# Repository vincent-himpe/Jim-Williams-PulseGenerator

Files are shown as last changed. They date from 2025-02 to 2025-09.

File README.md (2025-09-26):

# Jim-Williams-PulseGenerator
 Jim Williams Pulsegenerator, SiliconvalleyGarage Edition

## MK-III Features:

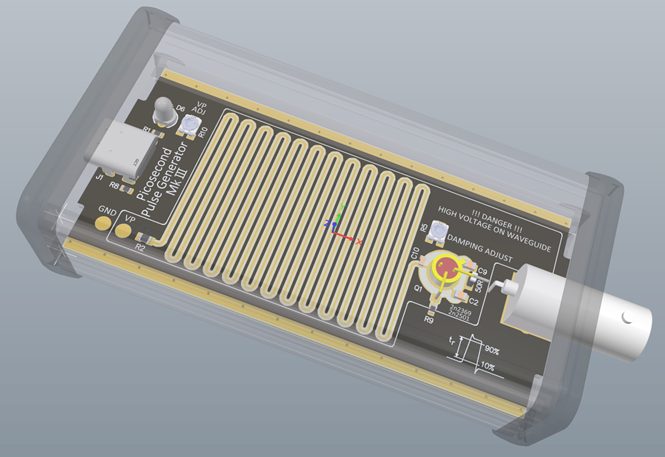
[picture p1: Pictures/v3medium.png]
mk-iii


The Mark-III is a big rework

- Switched to a metal case
- Switched to a BNC connector with floating center electrode
- Added damping adjust to compensate overshoot
- Reworked the waveguie "long capacitor" to take advantage of 4 layer board
- Different swithing regulator that is much cheaper than the LT1377.
- 5-stage high voltage cascade
- trimming adjustment for avalanche voltage
- USB-C power connection. No more batteries.
- Endcaps for both sides as a predrilled PCB that fit the Hammond Enclosure
  
## Layout

The Board is a 4 layer PCB that can easily be produced by the likes of JLCPCB or PCBway.  A full production pack (Gerber / NCdrill, BOM , Pick and place ) is available. 

## Assembly

The Bom and pick and place is included for assembly using LCSC parts at JLCPCB. The BOM also includes MOUSER part numbers

## Source Files

All source files are available in Altium Format. That's what i know, have and use. Other CAD programs most likely can import those. So you can modify.

## License

The project is PUBLIC DOMAIN. Do as you please. No warranties, As-Is
Creative Commons Zero.

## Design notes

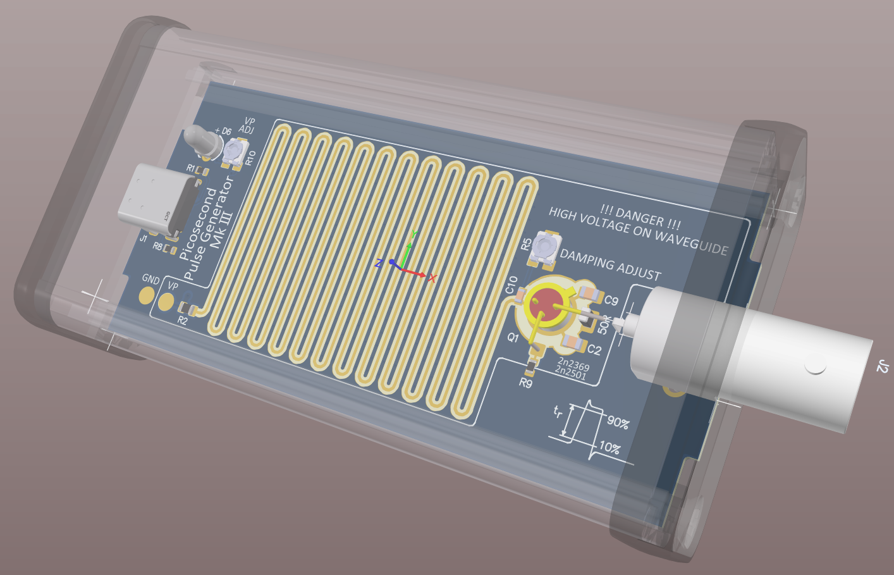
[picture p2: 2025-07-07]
Pictures/MK-III.png

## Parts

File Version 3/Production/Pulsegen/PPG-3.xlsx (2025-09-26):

Description | Designator | Quantity | LCSC
CAPACITOR,CERAMIC,470nF,250V,X7R,1210, CAPACITOR,CERAMIC,2pF,250V,C0G,0805,HIQ, CAPACITOR,CERAMIC,10pF,50V,C0G,0603, DIODE,SCHOTTKY,150V,1A,SK115,DO214AC(SMA), LED,TH,GREEN,42mCd,3MM, CONN,BNC,RA, ENCLOSURE,ALU.EXTRUDED,3.2inX1.8inX0.99in, TRANSISTOR, 2N2369 OR 2N2501, GOLD PINS, NOT 'A' VERSION, RESISTOR,1M,1%,125mW,0805, RESISTOR,12K,1%,100mW,0603 (1608), RES,TRIM,SMD,100R, RESISTOR,1K2,1%,100mW,0603 (1608), RES,TRIM,SMD,10K, PMIC,BOOST,LM2733,600KHz,SOT23-5 | C1, C2, C3, C4, C7, C8, C9, C10, D1, D2, D3, D4, D5, D6, J2, M1, Q1, R2, R4, R5, R6, R10, U1 | 23
CAPACITOR,CERAMIC,10uF,25V,X5R,0805 | C5, C6, C11, C12 | 4 | C3039694
CAPACITOR,CERAMIC,1nF,250V,X7R,0603 | C13 | 1 | C277510
FERRITE,1KZ@100MHz,0R2DC,0603 | FB1 | 1 | C160982
CONN,USB-C,16P,RA,TH,8.94X9.17 | J1 | 1 | C7095263
IND,10uH,1.2A,3X3, LQH3NPZ100MMEL | L1 | 1 | C701168
RESISTOR,5K1,1%,100mW,0603 (1608) | R1, R8 | 2 | C105580
RESISTOR,1K,1%,100mW,0603 (1608) | R3 | 1 | C22548
RESISTOR,4K7,1%,100mW,0603 (1608) | R7 | 1 | C99782
RESISTOR,10K,1%,100mW,0603 (1608) | R9 | 1 | C98220

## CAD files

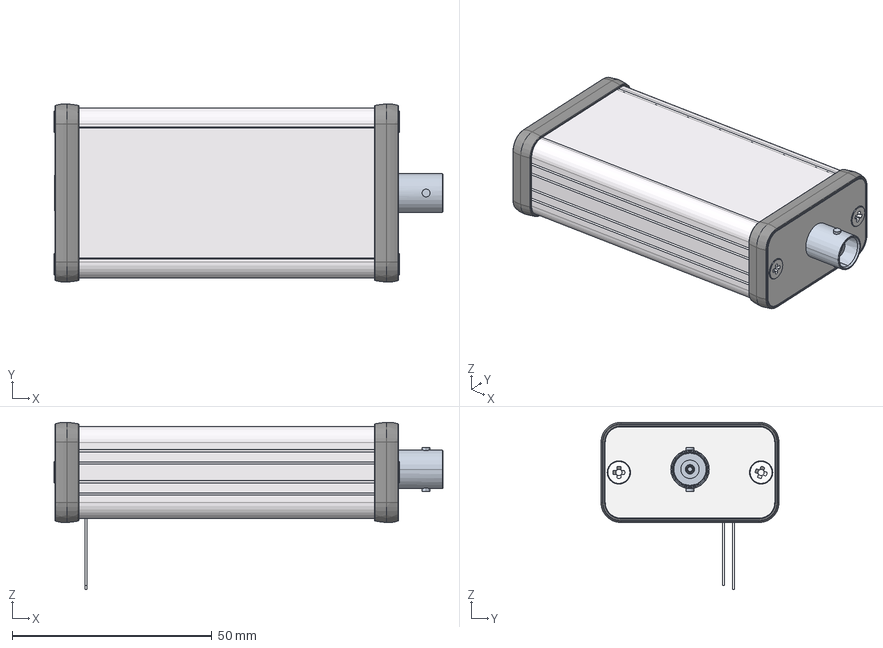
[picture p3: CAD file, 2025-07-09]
Version 3/JWpulsegen-V3.step
97.4 x 44.6 x 41.9 mm
MLCC capacitor 0603 - 0.5mm x 2
15103xxx
Chip Inductor 0603
MLCC capacitor 0805 - 0.85mm x 6
MLCC capacitor 1210 - 2.0mm x 5
SMA (DO-214AC) x 5
SOT23-5
SW3dPS-R0603 x 7
LQH3NPZ100MMEL
to18
User Library-1206 SMD Resistor
User Library-R0805
USB4085-GF-A_PART1
GCT
Extrusion Tube w. Inlay 80mm
Bezel Open x 2
End Plate x 2
1455 screw x 4

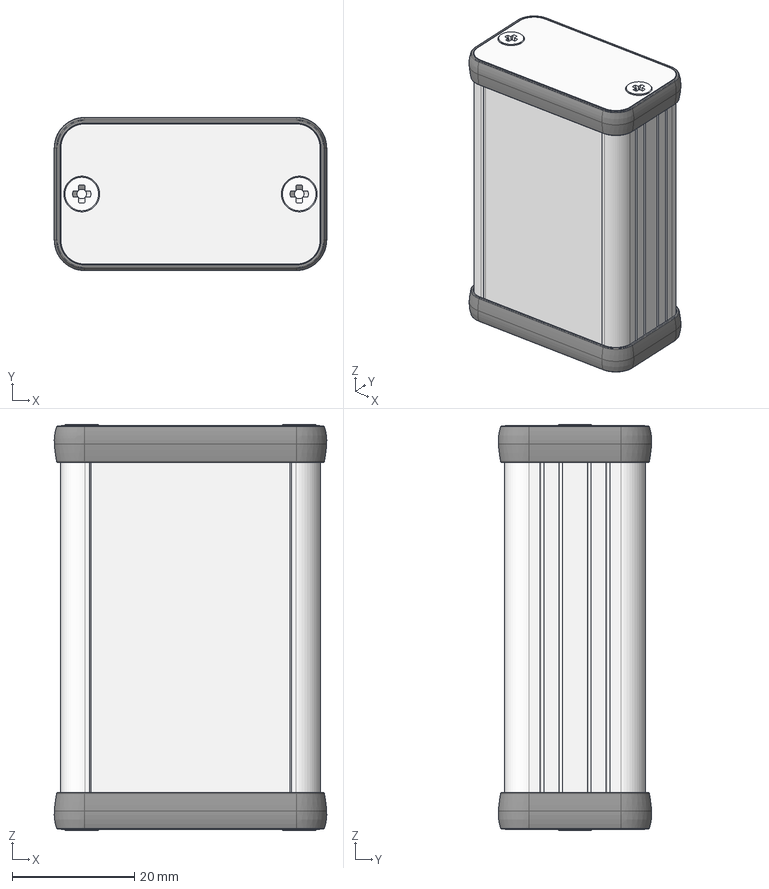
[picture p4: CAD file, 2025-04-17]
Version 3/STEP files/1455D601.stp
44.6 x 25.1 x 66.5 mm
Extrusion Tube w. Inlay 60mm
Bezel Open x 2
End Plate x 2
1455 screw x 4

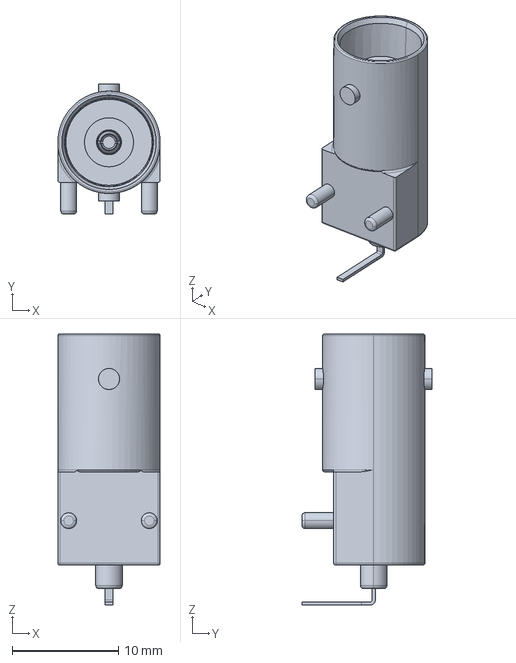
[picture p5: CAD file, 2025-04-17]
Version 3/STEP files/731000105.stp
9.65 x 12.3 x 25.6 mm

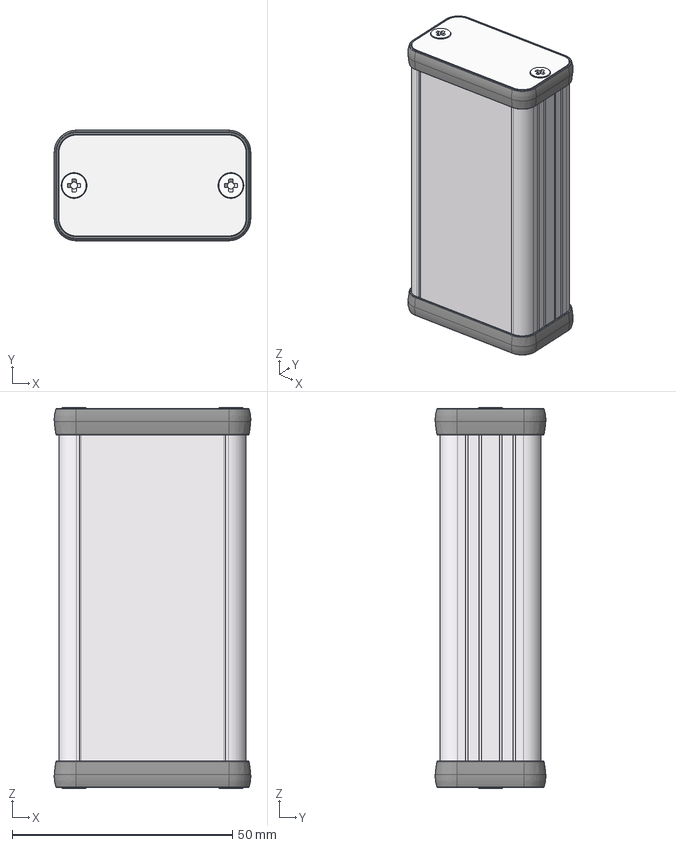
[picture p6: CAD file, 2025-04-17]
Version 3/STEP files/1455D801.stp
44.6 x 25.1 x 86.5 mm
Extrusion Tube w. Inlay 80mm
C Bezel Open x 2
C End Plate x 2
1455 screw x 4

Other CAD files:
Jim Williams Pulsegen/pulsegen-v2.DWG

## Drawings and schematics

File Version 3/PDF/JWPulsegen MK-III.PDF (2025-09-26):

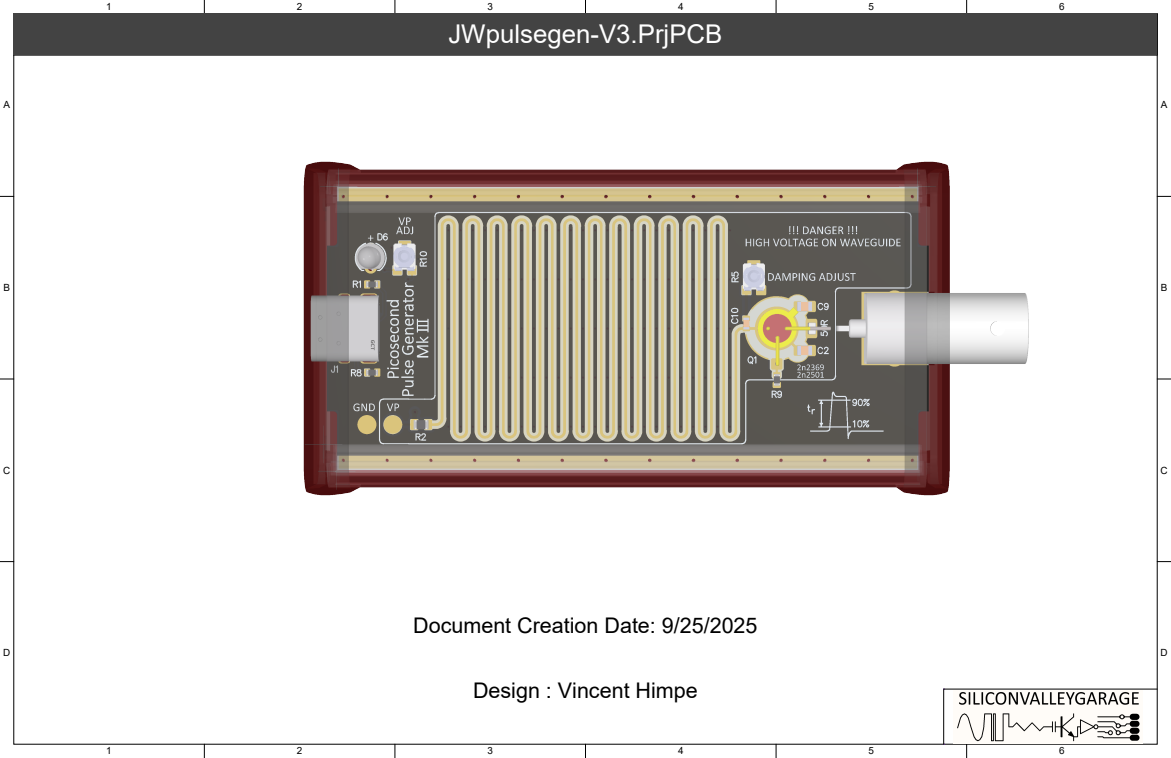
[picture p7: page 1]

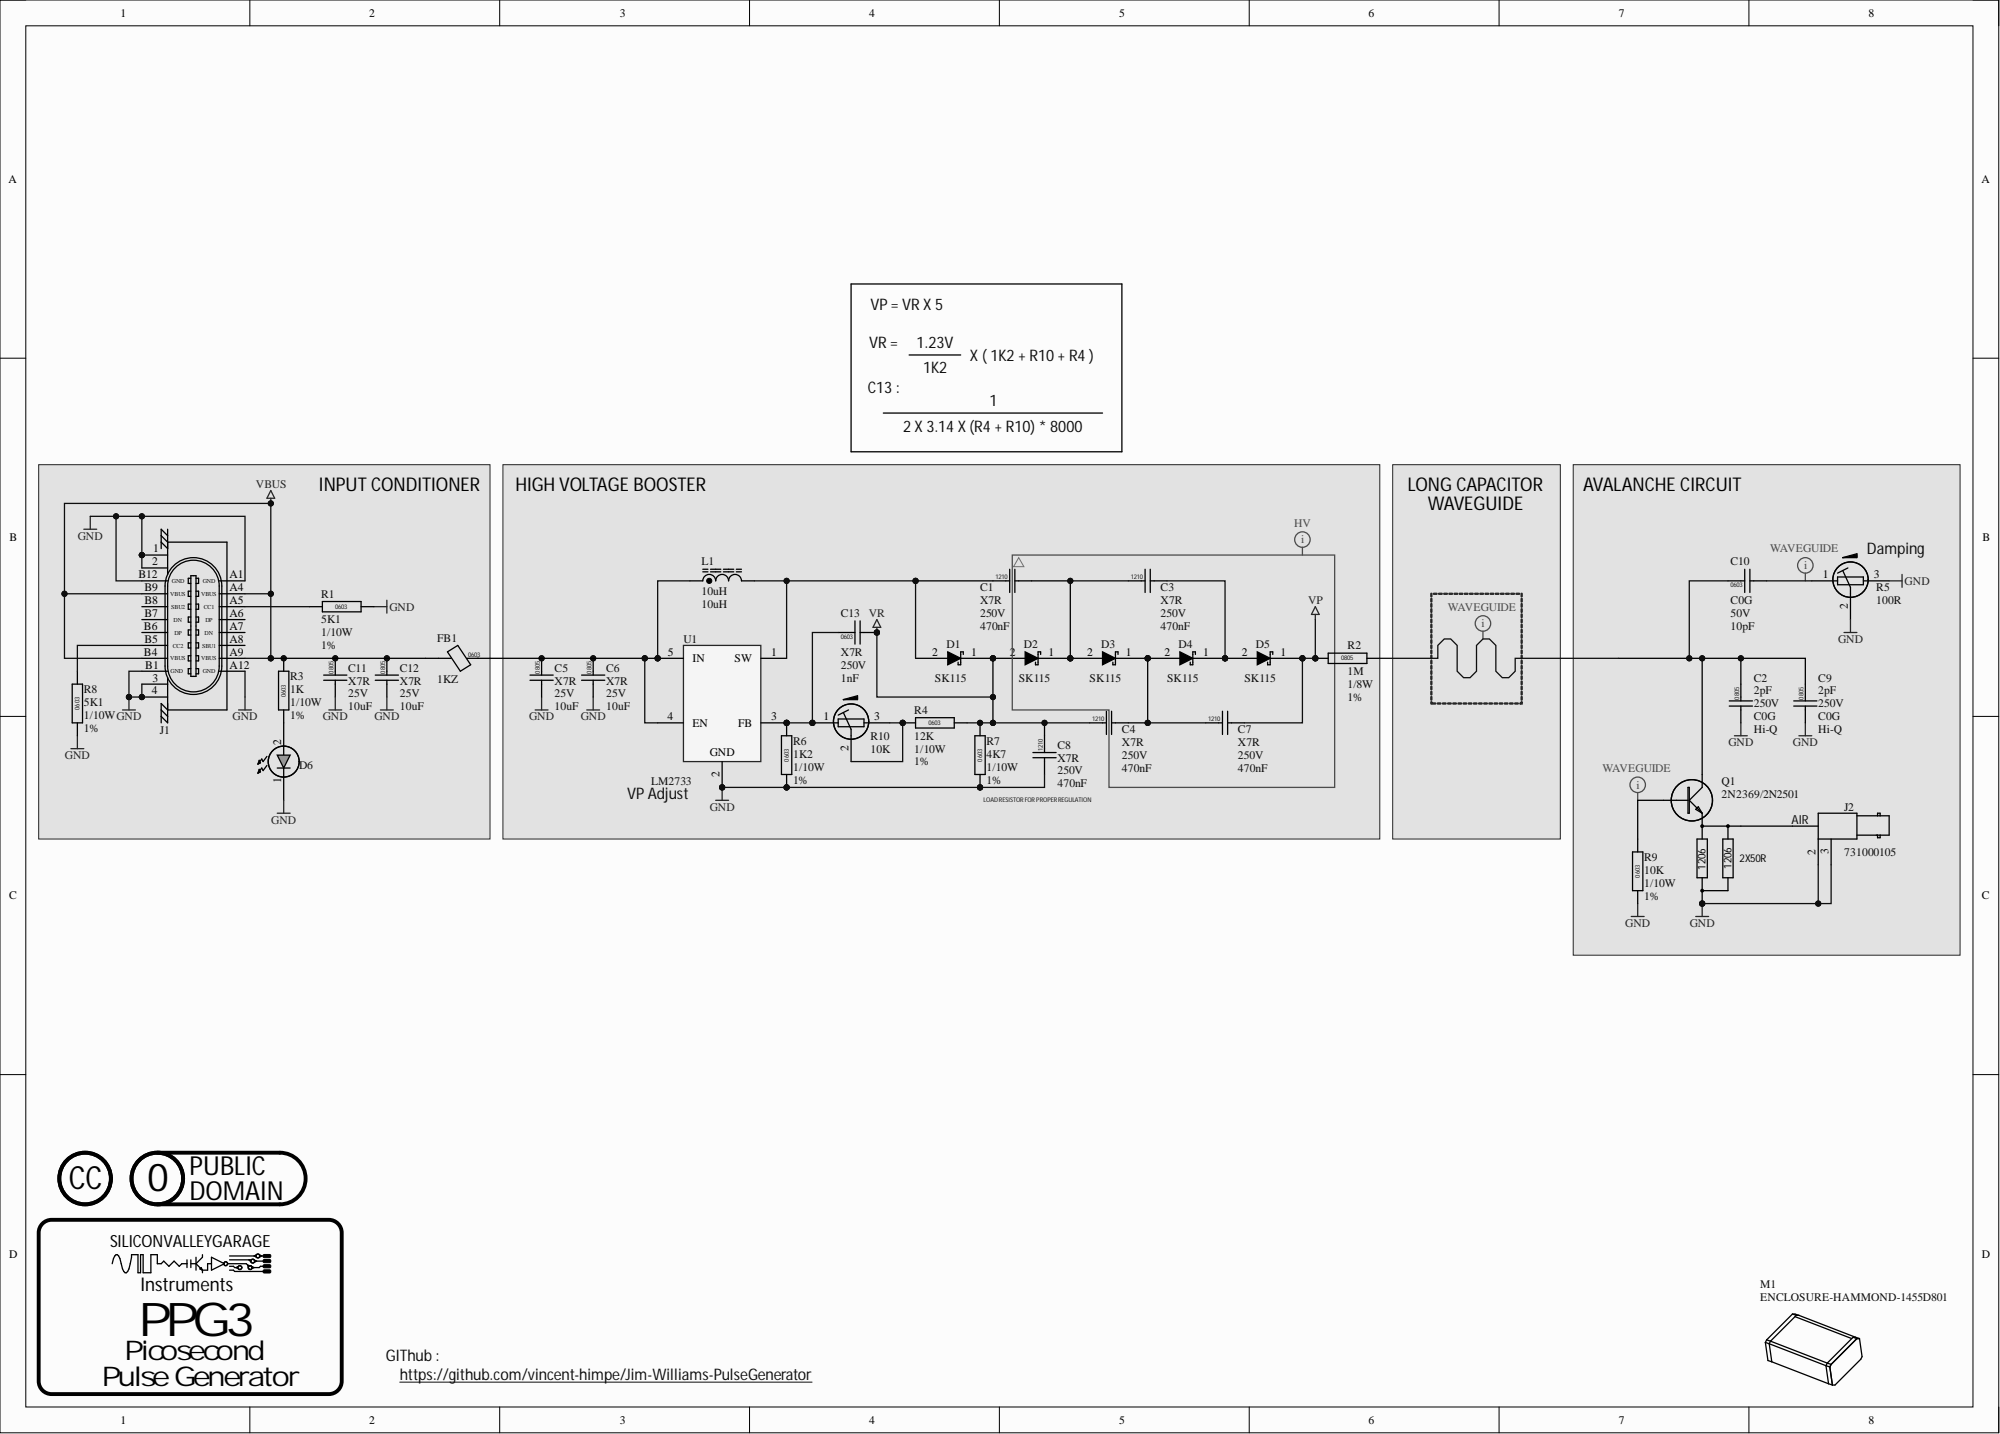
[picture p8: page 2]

LOADRESISTOR FOR PROPER REGULATION

GIThub :
https://github.com/vincent-himpe/Jim-Williams-PulseGenerator

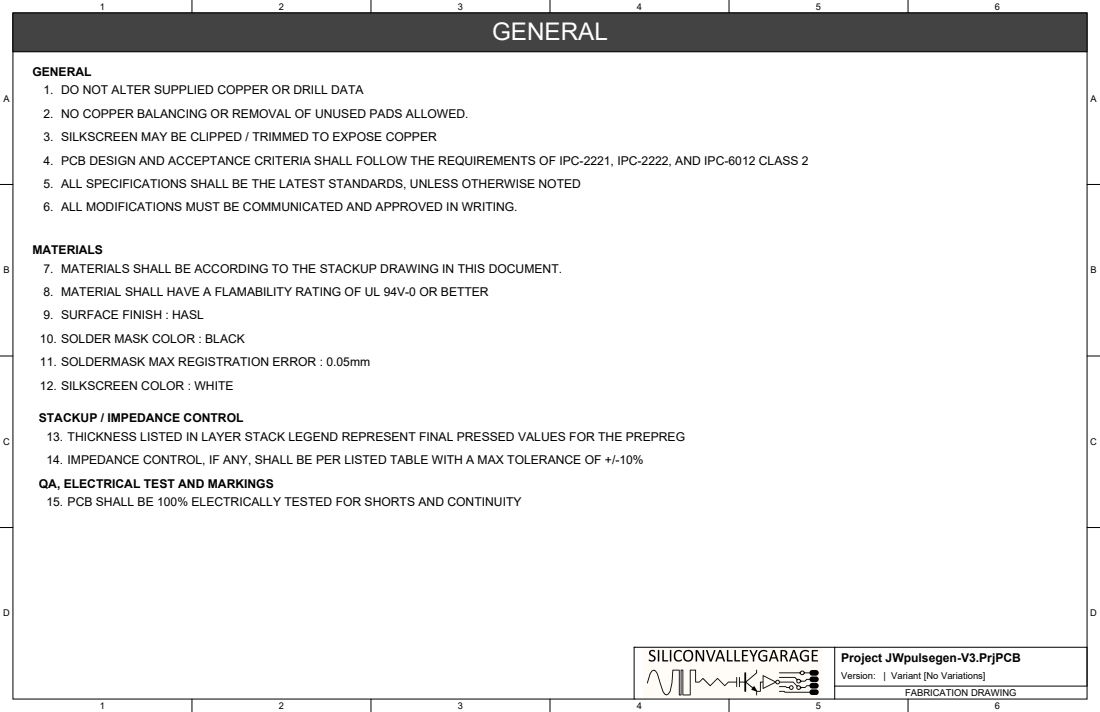
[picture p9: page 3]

GENERAL
1. DO NOT ALTER SUPPLIED COPPER OR DRILL DATA
2. NO COPPER BALANCING OR REMOVAL OF UNUSED PADS ALLOWED.
3. SILKSCREEN MAY BE CLIPPED / TRIMMED TO EXPOSE COPPER
4. PCB DESIGN AND ACCEPTANCE CRITERIA SHALL FOLLOW THE REQUIREMENTS OF IPC-2221, IPC-2222, AND IPC-6012 CLASS 2
5. ALL SPECIFICATIONS SHALL BE THE LATEST STANDARDS, UNLESS OTHERWISE NOTED
6. ALL MODIFICATIONS MUST BE COMMUNICATED AND APPROVED IN WRITING.

MATERIALS
7. MATERIALS SHALL BE ACCORDING TO THE STACKUP DRAWING IN THIS DOCUMENT.
8. MATERIAL SHALL HAVE A FLAMABILITY RATING OF UL 94V-0 OR BETTER
9. SURFACE FINISH : HASL
10. SOLDER MASK COLOR : BLACK
11. SOLDERMASK MAX REGISTRATION ERROR : 0.05mm
12. SILKSCREEN COLOR : WHITE

STACKUP / IMPEDANCE CONTROL
13. THICKNESS LISTED IN LAYER STACK LEGEND REPRESENT FINAL PRESSED VALUES FOR THE PREPREG
14. IMPEDANCE CONTROL, IF ANY, SHALL BE PER LISTED TABLE WITH A MAX TOLERANCE OF +/-10%
QA, ELECTRICAL TEST AND MARKINGS
15. PCB SHALL BE 100% ELECTRICALLY TESTED FOR SHORTS AND CONTINUITY

Project JWpulsegen-V3.PrjPCB
Version: | Variant [No Variations]

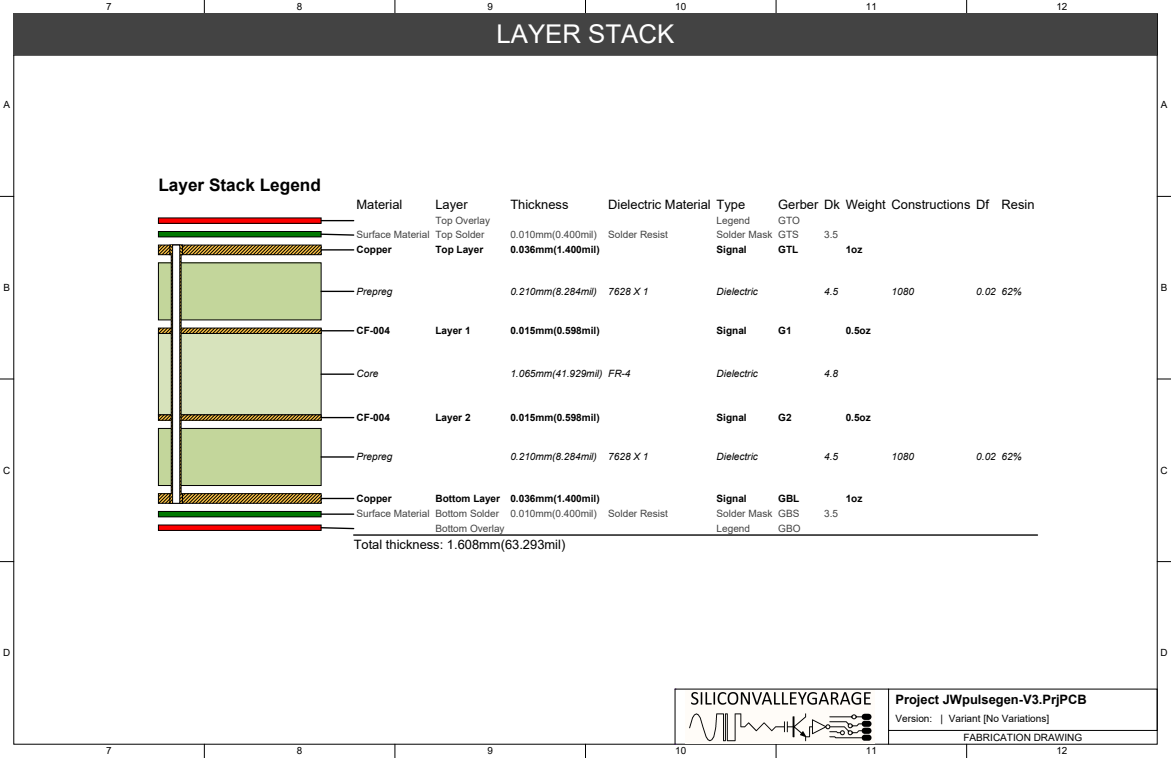
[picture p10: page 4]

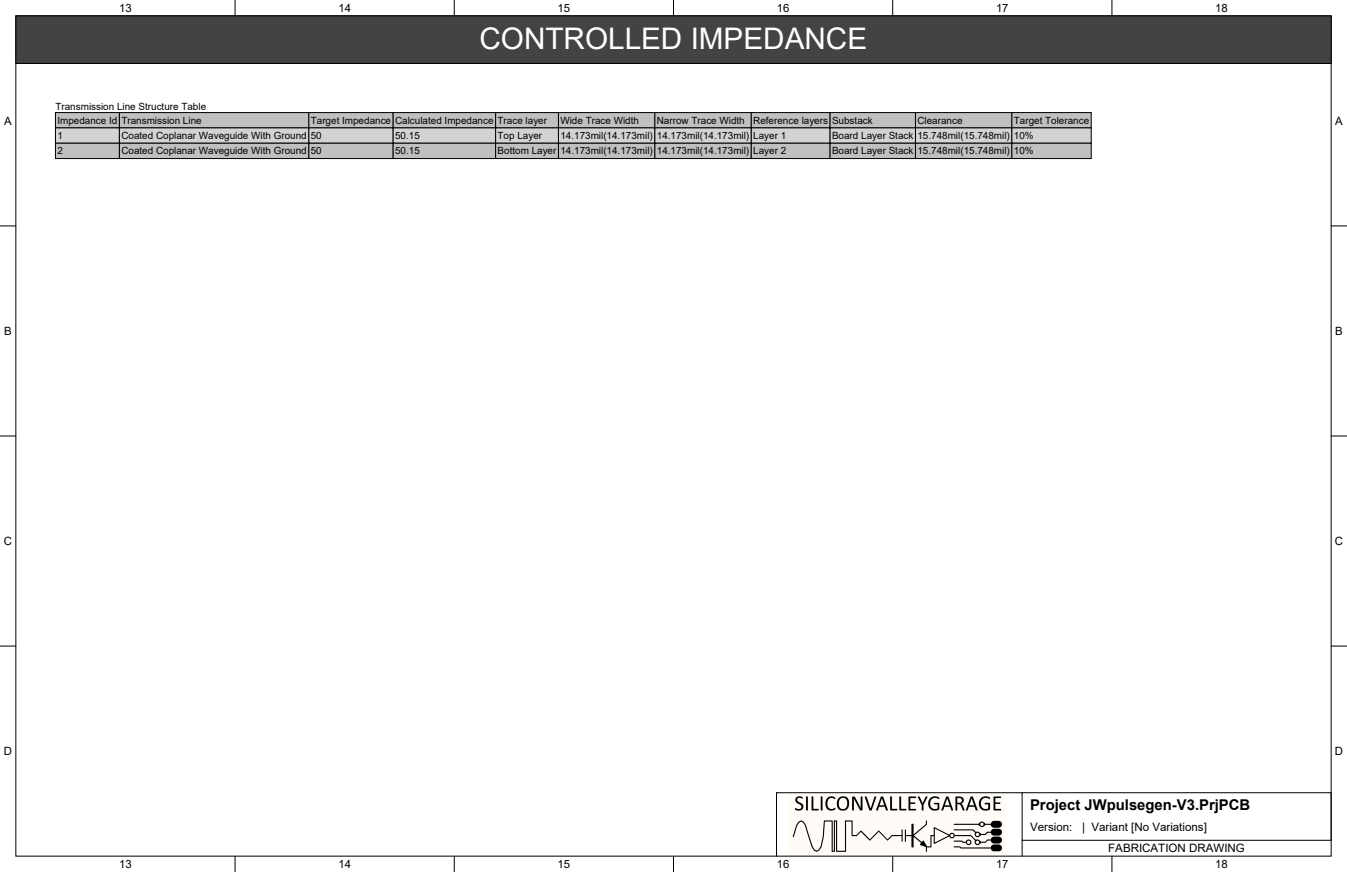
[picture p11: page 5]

Transmission Line Structure Table

Impedance Id | Transmission Line | Target Impedance | Calculated Impedance | Trace layer | Wide Trace Width | Narrow Trace Width | Reference layers | Substack | Clearance | Target Tolerance
1 | Coated Coplanar Waveguide With Ground | 50 | 50.15 | Top Layer | 14.173mil(14.173mil) | 14.173mil(14.173mil) | Layer 1 | Board Layer Stack | 15.748mil(15.748mil) | 10%
2 | Coated Coplanar Waveguide With Ground | 50 | 50.15 | Bottom Layer | 14.173mil(14.173mil) | 14.173mil(14.173mil) | Layer 2 | Board Layer Stack | 15.748mil(15.748mil) | 10%

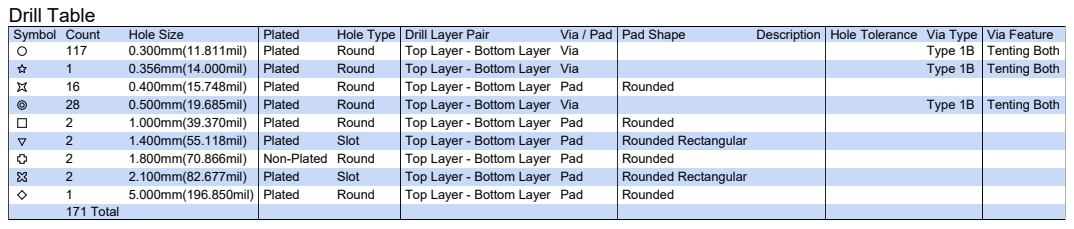
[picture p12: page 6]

Symbol | Count | Hole Size | Plated | Hole Type | Drill Layer Pair | Via / Pad | Pad Shape | Description | Hole Tolerance | Via Type | Via Feature

117 | 0.300mm(11.811mil) | Plated | Round | Top Layer - Bottom Layer | Via | | | | Type 1B | Tenting Both
1 | 0.356mm(14.000mil) | Plated | Round | Top Layer - Bottom Layer | Via | | | | Type 1B | Tenting Both
16 | 0.400mm(15.748mil) | Plated | Round | Top Layer - Bottom Layer | Pad | Rounded
28 | 0.500mm(19.685mil) | Plated | Round | Top Layer - Bottom Layer | Via | | | | Type 1B | Tenting Both
2 | 1.000mm(39.370mil) | Plated | Round | Top Layer - Bottom Layer | Pad | Rounded
2 | 1.400mm(55.118mil) | Plated | Slot | Top Layer - Bottom Layer | Pad | Rounded Rectangular
2 | 1.800mm(70.866mil) | Non-Plated | Round | Top Layer - Bottom Layer | Pad | Rounded
2 | 2.100mm(82.677mil) | Plated | Slot | Top Layer - Bottom Layer | Pad | Rounded Rectangular
1 | 5.000mm(196.850mil) | Plated | Round | Top Layer - Bottom Layer | Pad | Rounded
171 Total

Drill Drawing View (Scale 4:1)

LAYER VIEW : TOP LAYER

LAYER VIEW : MID LAYER 1

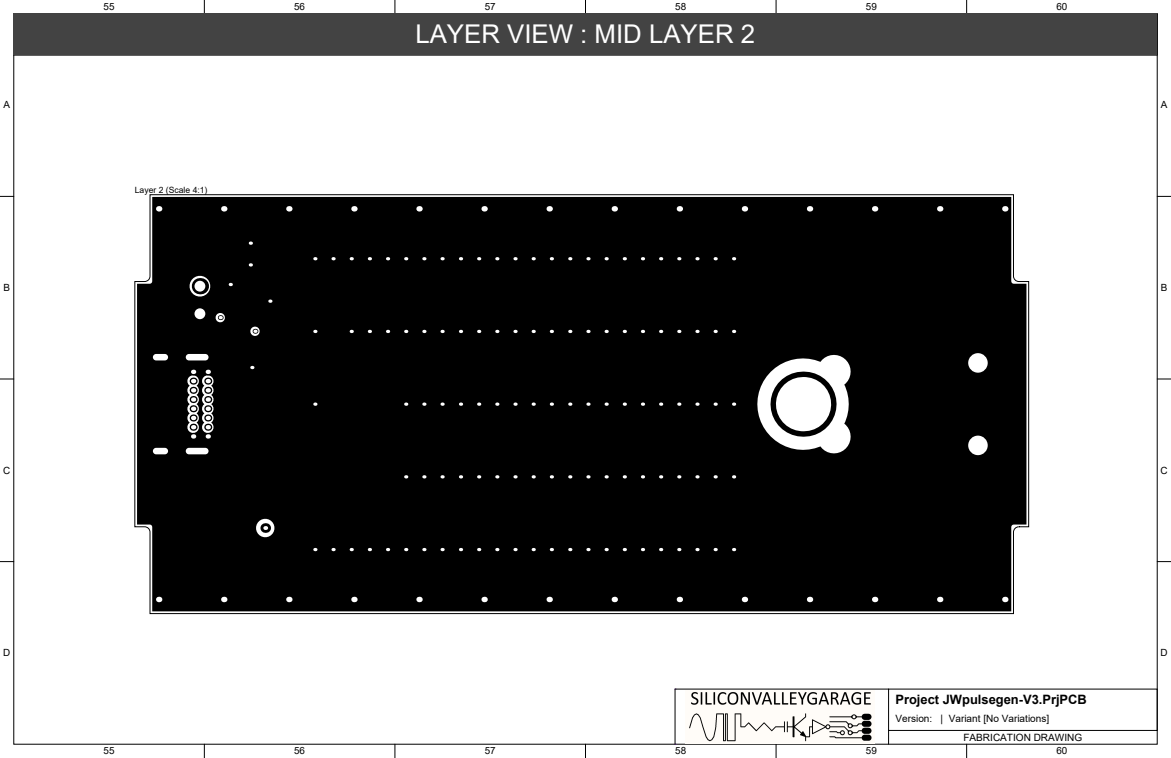
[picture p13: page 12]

LAYER VIEW : MID LAYER 2

LAYER VIEW : BOTTOM LAYER

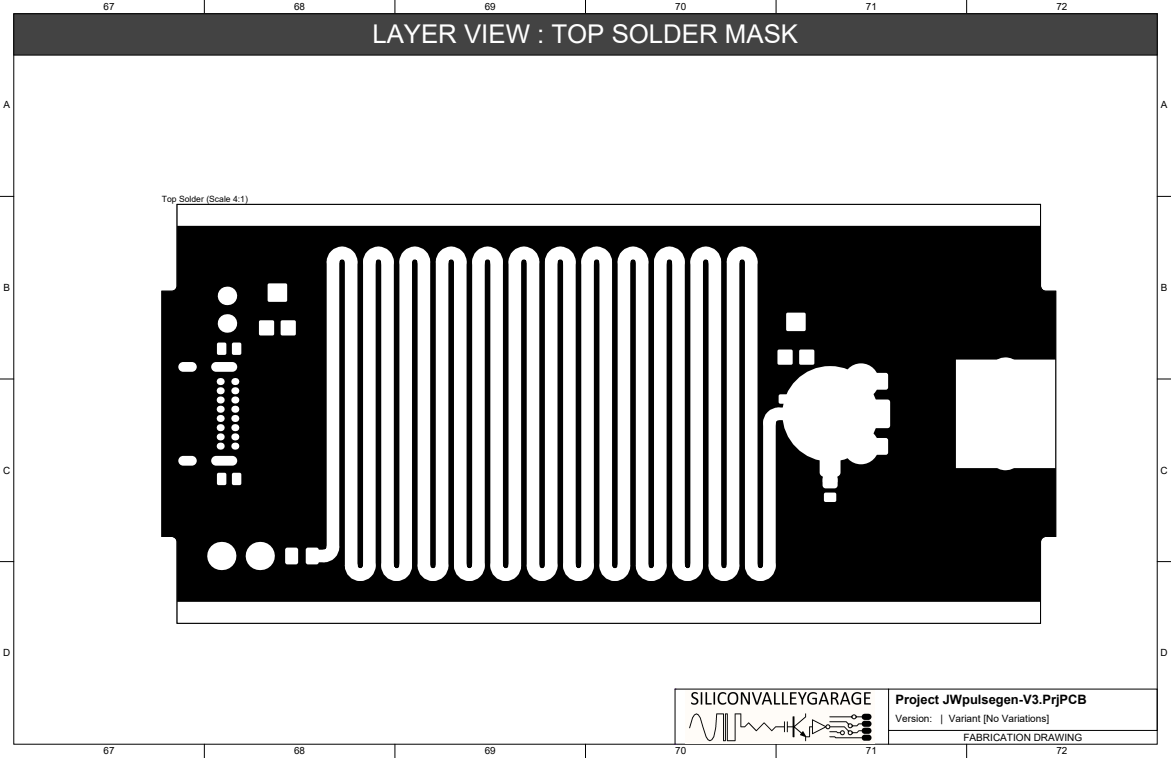
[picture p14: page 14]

LAYER VIEW : TOP SOLDER MASK

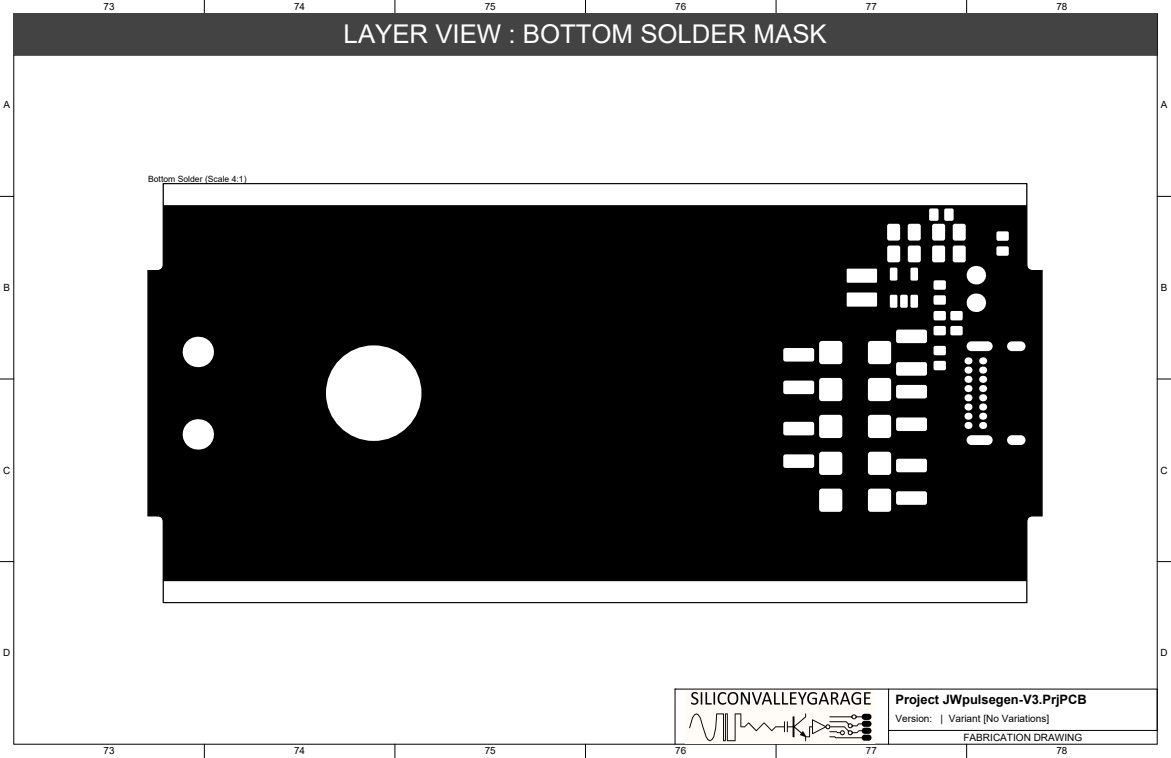
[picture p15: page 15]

LAYER VIEW : BOTTOM SOLDER MASK

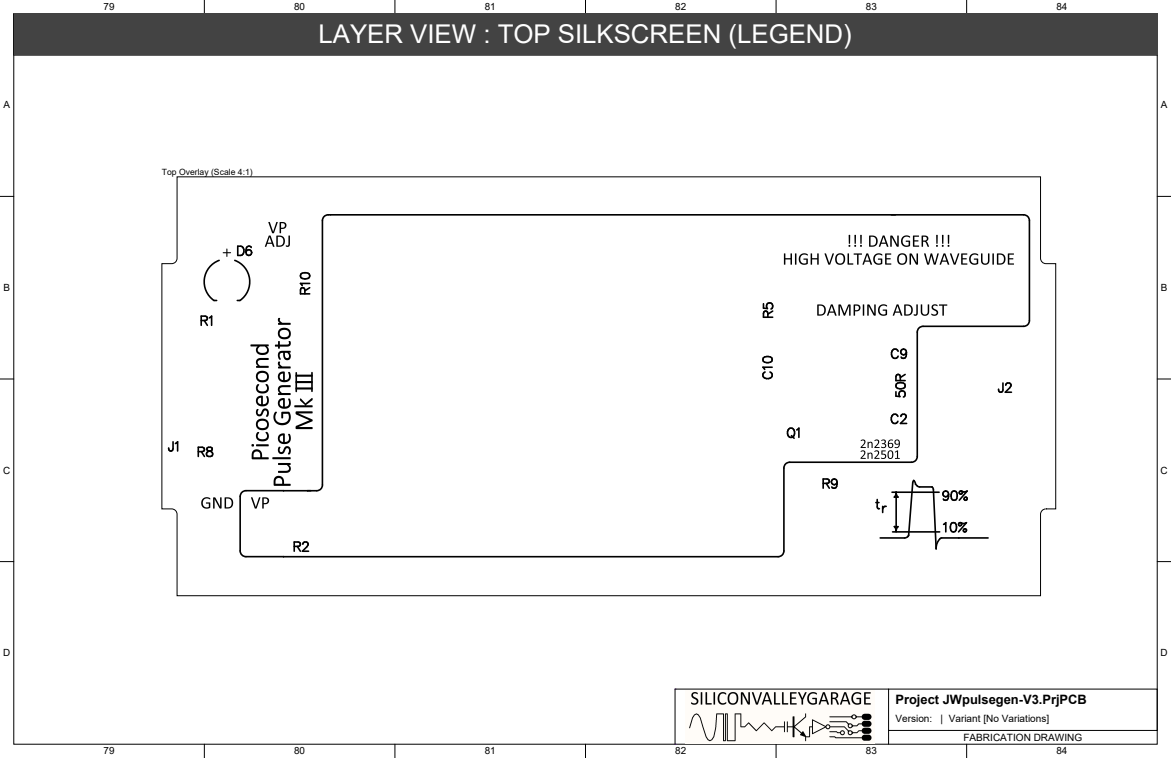
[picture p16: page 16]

LAYER VIEW : TOP SILKSCREEN (LEGEND)

LAYER VIEW : BOTTOM SILKSCREEN (LEGEND)

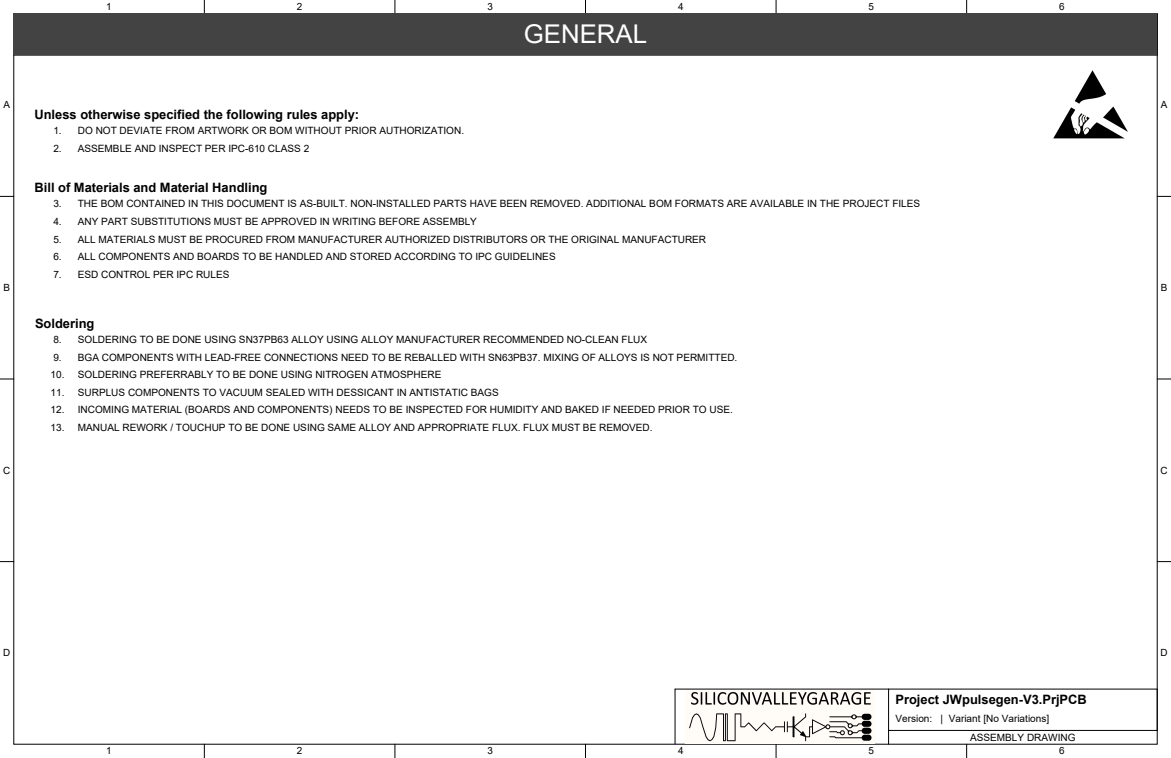
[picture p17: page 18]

Unless otherwise specified the following rules apply:
1. DO NOT DEVIATE FROM ARTWORK OR BOM WITHOUT PRIOR AUTHORIZATION.
2. ASSEMBLE AND INSPECT PER IPC-610 CLASS 2

Bill of Materials and Material Handling
3. THE BOM CONTAINED IN THIS DOCUMENT IS AS-BUILT. NON-INSTALLED PARTS HAVE BEEN REMOVED. ADDITIONAL BOM FORMATS ARE AVAILABLE IN THE PROJECT FILES
4. ANY PART SUBSTITUTIONS MUST BE APPROVED IN WRITING BEFORE ASSEMBLY
5. ALL MATERIALS MUST BE PROCURED FROM MANUFACTURER AUTHORIZED DISTRIBUTORS OR THE ORIGINAL MANUFACTURER
6. ALL COMPONENTS AND BOARDS TO BE HANDLED AND STORED ACCORDING TO IPC GUIDELINES
7. ESD CONTROL PER IPC RULES

Soldering
8. SOLDERING TO BE DONE USING SN37PB63 ALLOY USING ALLOY MANUFACTURER RECOMMENDED NO-CLEAN FLUX
9. BGA COMPONENTS WITH LEAD-FREE CONNECTIONS NEED TO BE REBALLED WITH SN63PB37. MIXING OF ALLOYS IS NOT PERMITTED.
10. SOLDERING PREFERRABLY TO BE DONE USING NITROGEN ATMOSPHERE
11. SURPLUS COMPONENTS TO VACUUM SEALED WITH DESSICANT IN ANTISTATIC BAGS
12. INCOMING MATERIAL (BOARDS AND COMPONENTS) NEEDS TO BE INSPECTED FOR HUMIDITY AND BAKED IF NEEDED PRIOR TO USE.
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

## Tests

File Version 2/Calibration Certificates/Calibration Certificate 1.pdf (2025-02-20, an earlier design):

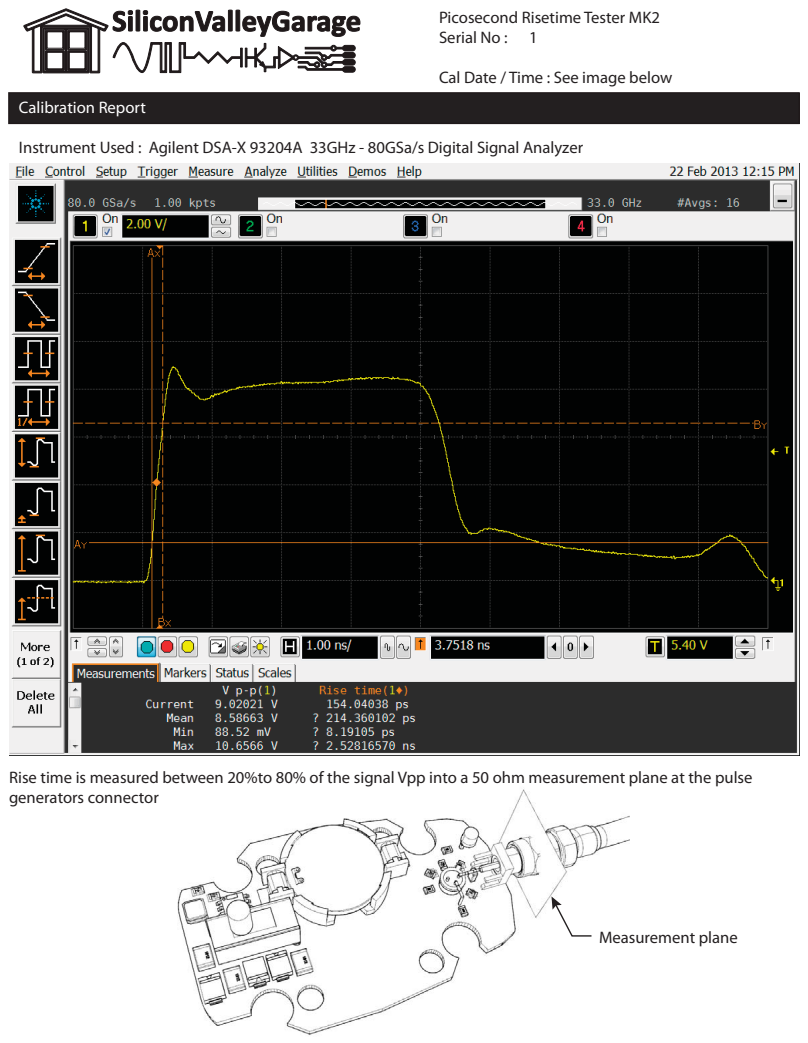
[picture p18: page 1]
Calibration Report; Measurement plane

Picosecond Risetime Tester MK2
Serial No :

Cal Date / Time : See image below

Instrument Used : Agilent DSA-X 93204A 33GHz - 80GSa/s Digital Signal Analyzer

Rise time is measured between 20%to 80% of the signal Vpp into a 50 ohm measurement plane at the pulse
generators connector

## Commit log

2025-02-20 initial push
    [PcbLib1.PcbLib, Schlib1.SchLib, pULSEGEN.PrjPCB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]
2025-04-16 mac repository added
    [PcbLib1.PcbLib, Schlib1.SchLib, pULSEGEN.PrjPCB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]
2025-07-07 REMOVE OLD FILES
    [JWpulsegen-V3.PcbLib, JWpulsegen-V3.SCHLIB]
2025-07-09 added endcaps and cosmetic tweaks
    [Bill of Materials-JWpulsegen-V3.csv, Bill of Materials-JWpulsegen-V3.xlsx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]
